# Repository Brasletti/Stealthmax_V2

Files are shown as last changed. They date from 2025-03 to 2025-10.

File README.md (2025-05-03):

# StealthMax V2 [RC1]– The New Filtration Beast!
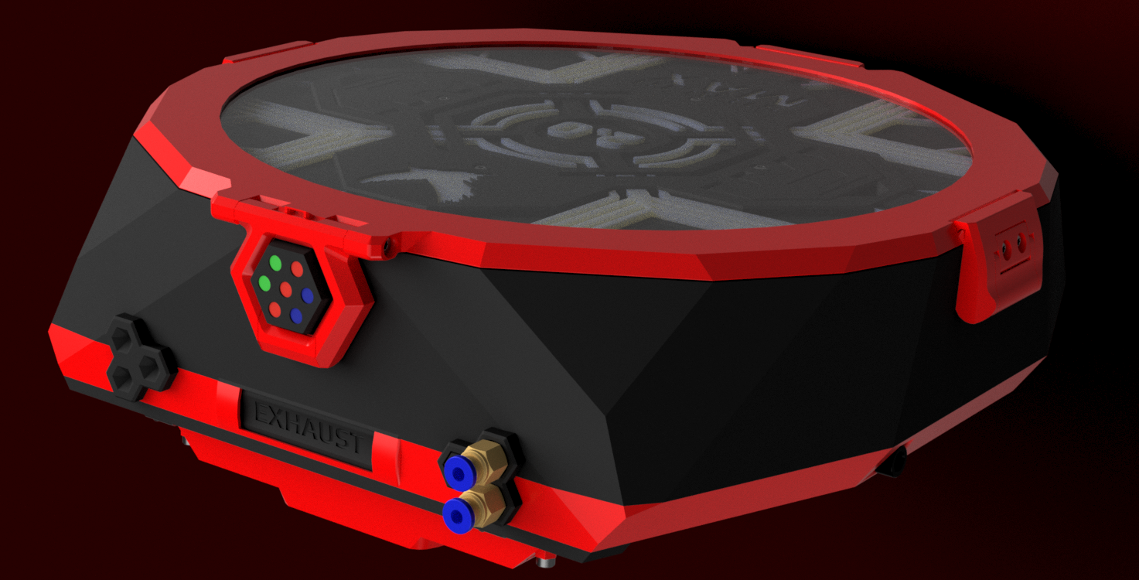
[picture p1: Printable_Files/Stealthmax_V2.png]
StealthMax V2

## Nevermore StealthMax was already the pinnacle of 3D printing filtration. How could we possibly improve it? Here's how:

---

## 🛡️ **The HEPA Filter**

A significant enhancement in filtration efficiency comes from adopting our new industrial-grade H14 HEPA filter, offering superior performance without compromising airflow. Gone are the days of relying on generic, uncertified robotic vacuum filters!

**Why the upgrade?**  
The Xiaomi robovac filters used in our V1 model lacked an official HEPA rating, typically indicating below-HEPA (≤H10) performance, casting doubt on their effectiveness in capturing ultra-fine particles (UFPs). Since FDM 3D printers primarily emit UFPs and volatile organic compounds (VOCs), using a filter specifically designed and rated to handle these pollutants efficiently is crucial.
<BR><BR>Some might be disappointed this is not an off-the-shelf component. While this is what we usually strive for, there are simply no H14 HEPA filters in a suitable size, and its especially hard (impossible?) finding H14 quality filtration at a price point below $12 - please check on amazon or the likes. At a (6-) 12 month per filter lifetime, Nevermore H14 is less than a dollar per month of use. We try to bring professional filtration to the home user, without charging a premium for it! 

Our new HEPA filter:
- Is **99.995% efficient** at capturing particulates (**H14 standard**).
- Outperforms typical robotic vacuum filters by capturing up to **2000 times more particulates** per filtration pass.
- Specifically excels at capturing ultra-fine particles (UFPs: PM0.01 – PM0.1) emitted during FDM 3D printing—particles that thinner, inferior filters struggle to handle effectively.
- Uses top and bottom sealing foam to force air through the filter and not pass through gaps in the filter unit.

**Nevermore3D proudly offers the highest-grade HEPA filtration available for FDM 3D printing. UFPs: YOU SHALL NOT PASS!**

---
## 🚀 **The Fan**

With the GPU fan from V1 becoming increasingly rare due to evolving GPU cooler designs, we searched far and wide for a powerful, reliable replacement capable of pulling substantial airflow through dense filtration media. **We found it!**

The new **StealthMax V2 7020 fan** (MX7020GBH2) delivers **twice the airflow** at the **same noise level**, meaning:
- Quieter operation at equivalent airflow.
- Efficient filtration of larger chamber volumes.
- Has twice the static pressure.

Moreover, by being slimmer than its predecessor it makes room for even more HEPA surface area, decreasing the pressure drop and maintaining maximum airflow! And since it's not an end-of-life (EOL) design, it should remain available for years to come! Also, contrary to any rumours, its certainly not proprietary!

---

## ⚙️ **The Servo-Controlled Vent**

While StealthMax V1 had an adjustable exhaust vent for controlling chamber temperatures when printing PLA, the solution wasn't optimal. Now, StealthMax V2 upgrades this feature with a **servo-controllable exhaust vent**, enabling:

- Automatic switching between exhaust and recirculation modes, tailored to your specific printing material.
- Chamber temperature management by venting air automatically whenever the chamber exceeds your specified temperature threshold.

---

## 💡 **Intelligent Signaling**

StealthMax V2 adds smart visual signaling (pending future software update), making it easy to monitor your filter status at a glance:

- **Neopixel LEDs** indicating filter function status and carbon replacement intervals.
- LEDs can be installed at the Bowden caps or the main hinge.
- Optional support for a sleek **1.28" LED display** or **KNOMI 2** mounted at the main hinge for the ultimate monitoring and customization experience (currently limited software support).

---

## 🔌 **Expanded Accessibility**

StealthMax V2 dramatically improves user accessibility and versatility:

- **Multiple Bowden tube access points** on every side for clean and easy routing.
- **Up to 6 simultaneous Bowden tubes** supported for complex tool-changer setups. Bowden routing is much improved too, reducing unneccessary filament drag.
- Integrated routing for your **PUG umbilical cable**.
- Convenient additional **CPAP intake ports** at the bottom, allowing flexible air routing throughout your machine.

---

## ❄️ **Carbon Cooler (Optional Add-On) [Kit ready: Summer 2025]**

Let's face it—activated carbon filtration becomes less effective as temperature rises, yet we require high chamber temperatures for optimal printing with most advanced filaments. StealthMax V2 is designed with this challenge in mind, supporting an optional **Carbon Cooler module**:

- **Peltier cooling** chills intake air, increasing carbon adsorption efficiency.
- The hot side of the peltier then **reheats the filtered air**, and is recirculated back into the chamber, maintaining a hot environment where needed.
- Cooler carbon means more effective filtration, capturing VOCs longer, even at chamber temperatures up to 70°C.
- Due to peltier inefficiencies, a bit more waste heat will be generated, so expect a slight bump in chamber temps too - but if your chamber gets too hot we have a servo exhaust for that!

**Cool carbon, hot chamber? Check.**

---

## 🌞 **PCO (Photocatalytic Oxidation) Stage (Optional Add-On) [Kit ready: Fall 2025]**

StealthMax V2 comes ready for integration of an advanced **internal photocatalytic oxidation (PCO)** filtration stage:

- Utilizes **UV light-created hydroxyl radicals** to destroy volatile organic compounds (VOCs) that bypass carbon and HEPA stages.
- Mimics natural sunlight degradation of VOCs in outdoor environments.
- Degraded VOC molecules become easier to capture with subsequent carbon filtration passes, ultimately breaking down into harmless CO₂.

**Sunlight truly is the best disinfectant!**

---

## ✨ **Additional Improvements**

We've implemented numerous improvements to ensure a smoother user experience and better performance:

- Enhanced **print-in-place latch designs** for reliable, hassle-free prints.
- **Carbon container lid** now sits more securely, with additional bolts and improved geometry.
- Reduced material usage in the main chamber, optimized support structures, quicker-to-print carbon basket, better fitting lid and generally more refined.

---

## 🚧 **Installation & Documentation**

[Central3DPrinting Electronics Installation](https://docs.google.com/presentation/d/e/2PACX-1vQseX6O0ZcSdXpOdnfkClK4V5FH0Ed1FzcuMa7BvOZgEiaAOtqwpyQ51u74DkXTCRRQ-EDv1vXZ-xWn/pub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)
Comprehensive installation guide, BOM (Bill of Materials), and detailed documentation for assembly will be provided shortly.
| Category | Item | Quantity | Notes |
|---|---|---|---|
| **Connectors**  | [Wago 221-413](https://s.click.aliexpress.com/e/_oDV7bC9) | 2 | |
| | [Wago 221-412](https://s.click.aliexpress.com/e/_oDV7bC9) | 2 | |
| | M6 PC4 Bowden connector | 1–6 | Typically 1; M10 optional at bottom slot only |
| **Fasteners** | M6 x 6mm | 2 | Plugs side PC4 M6 Bowden openings |
| | 2020 extrusion T-nut | 2 | |
| | M3 inserts (L=4 mm, OD=5 mm) | 42 | |
| | M2 x 6mm self-tapping screws | 5 | Pico + servo |
| | M3 x 6mm BHCS | 35 | Reduce quantity by 1 if not using intake sensor PCB |
| | M3 x 8mm SHCS | 1 | Omit if not using intake sensor sandwich |
| | M3 x 25mm SHCS | 8 | |
| | M3 x 6mm FHCS | 4 | Reduce quantity by 1 if not using spacer for 3mm back panels |
| | M3 x 10mm BHCS | 3 | |
| | M3 x 16mm SHCS | 4 | |
| **Electronics** | Same as StealthMax V1 | - | Excludes buck converter; replaces DC plug+BT with Microfit 5p for USB; adds Pico pins GP12-15 for Neopixel and FT90M servo |
| |[7-bit neopixel hinge display](https://s.click.aliexpress.com/e/_oorL68t) | 1 | Optional. |
| |[1,28" hinge display](https://s.click.aliexpress.com/e/_olAkf37) | 1 | Optional. Touch version without touch cables easier to install. Non-touch version needs thinner [awg 28 wires](https://s.click.aliexpress.com/e/_oFYgT37) to fit in the slot |
| |[FT90M Servo](https://s.click.aliexpress.com/e/_ol1TsBr) | 1 | Standard slot will fit FT90M, FT1190M servos. Version for [Emax ES08MA and MDII servos](https://s.click.aliexpress.com/e/_olzGGzx) also available |
| **Fan** | [TopFan MX7020GBH2](https://central3dprinting.com/products/nevermore-stealthmax-v2-fan?ref=NEVERMORE3D) | 1 | Will also fit the Sanyo C70 |
| **HEPA** | [Nevermore H14 HEPA](https://central3dprinting.com/products/nevermore-stealthmax-v2-h14-hepa-filter?ref=NEVERMORE3D) | 1 | 116mm OD x 42mm H |
| **Carbon** | [Nevermore](https://central3dprinting.com/products/nevermore-activated-carbon-for-voc-standard-xl-scorch?ref=NEVERMORE3D) | 1 | Nevermore Carbon, Nevermore Boost, Nevermore Scorch, or any tested quality, non-acid, 4mm activated carbon pellet. 2L will refill with some to spare. |

---

## 📢 **Community & Support**

We're dedicated to continuously improving StealthMax V2. Your feedback, testing, and suggestions are invaluable. Connect with us:

- **GitHub Issues:** Report issues or request enhancements directly here on GitHub.
- **[Discord Community](https://discord.gg/RgQP5cWHxj):** Join fellow makers and contributors for discussions, troubleshooting, and feature discussions.
- **[Check our Print Settings Wiki](https://github.com/nevermore3d/StealthMax/wiki/Print-Settings)** for additional tips and tricks!

---

**Happy printing, breathe easy, and stay stealthy!** 🚀🌬️
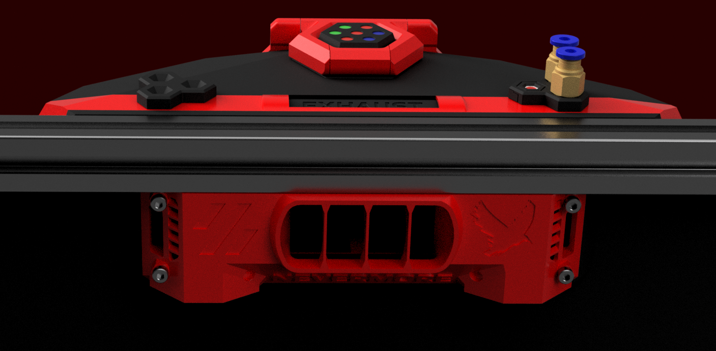
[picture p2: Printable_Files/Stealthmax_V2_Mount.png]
StealthMax V2 Mount


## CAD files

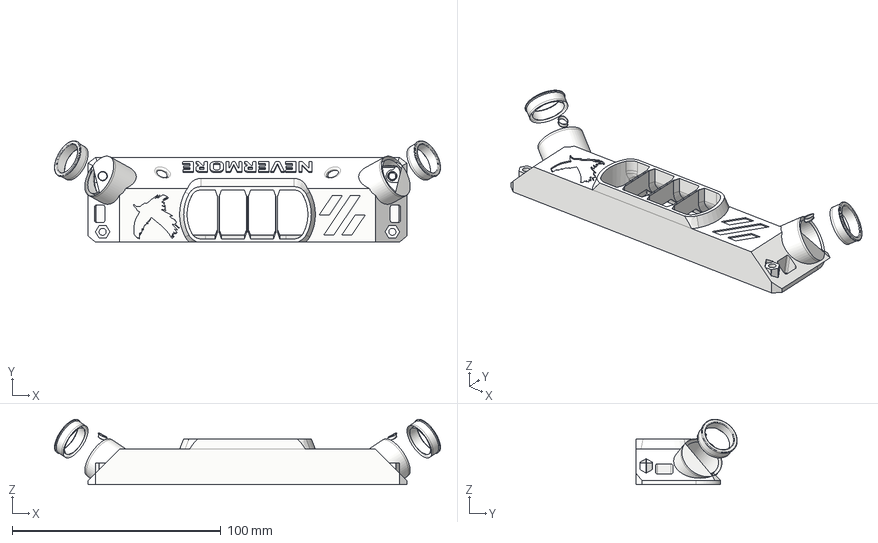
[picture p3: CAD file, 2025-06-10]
Printable_Files/0_Chamber_Side_Mounting/CPAP_Intakes/17mm_CPAP_Tube.step
185.0 x 48.7 x 31.3 mm

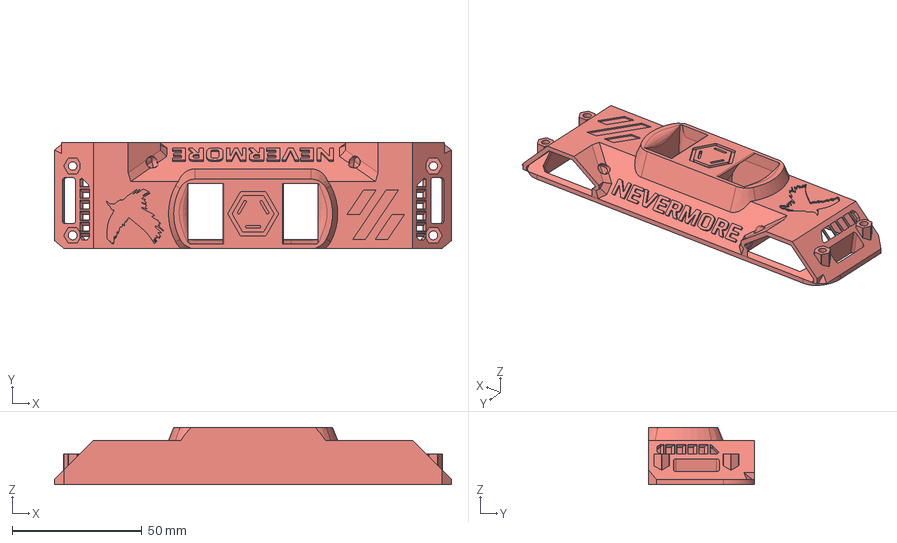
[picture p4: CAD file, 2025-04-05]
Printable_Files/0_Chamber_Side_Mounting/Exhaust_Diverter/EXHAUST_LATERAL_DIVERT(moving_bed).step
152.8 x 40.7 x 22.0 mm

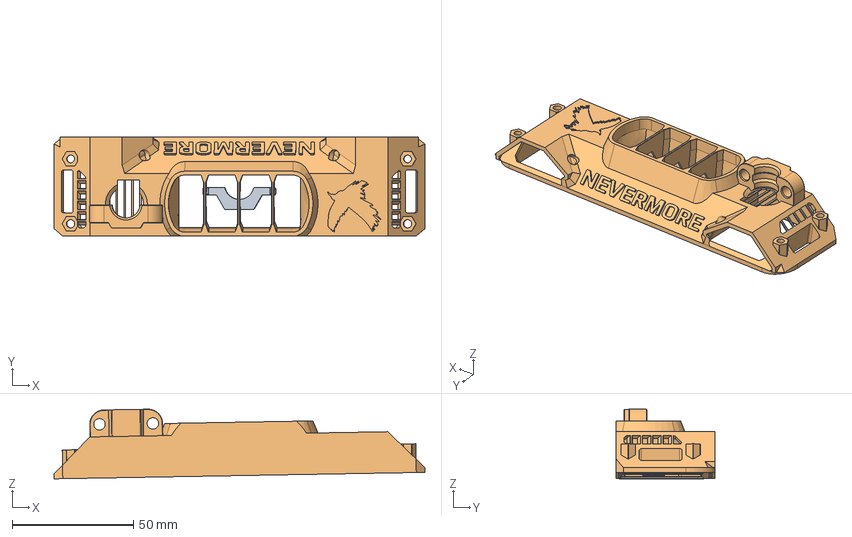
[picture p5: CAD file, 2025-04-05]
Printable_Files/0_Chamber_Side_Mounting/PUG_Wire_Routing/PUG_Chamber_Side.step
152.8 x 40.7 x 28.7 mm

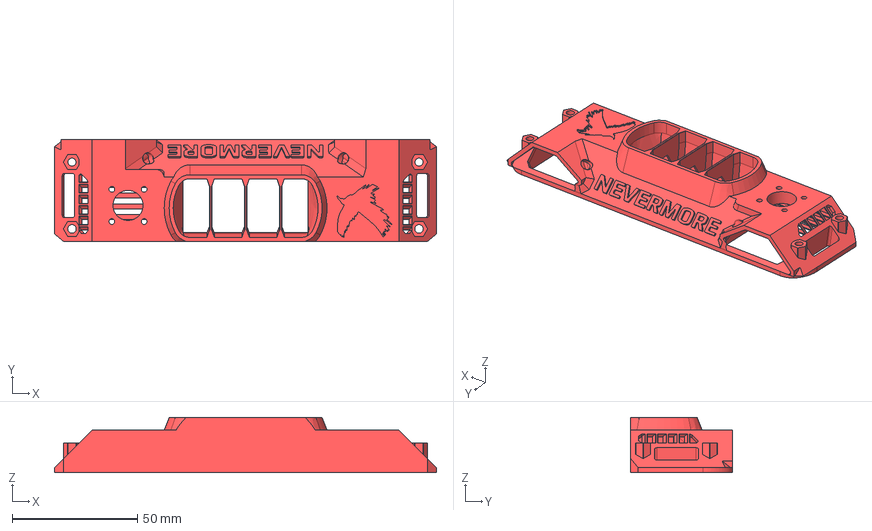
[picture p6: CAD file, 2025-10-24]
Printable_Files/0_Chamber_Side_Mounting/UserMods/Umbilical_CNLINKO_LP-12_Socket[Brasletti]/umbilical_cnlinko_lp12_intake.step
152.8 x 40.7 x 22.0 mm

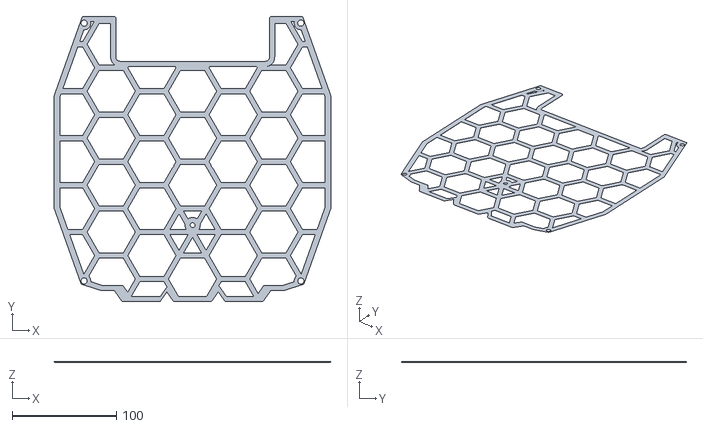
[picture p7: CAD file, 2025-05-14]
Printable_Files/1_Flow_Chamber/Back_Panel_Spacer[for_3mm_back_panel_thickness].stl
265.4 x 273.1 x 1.00

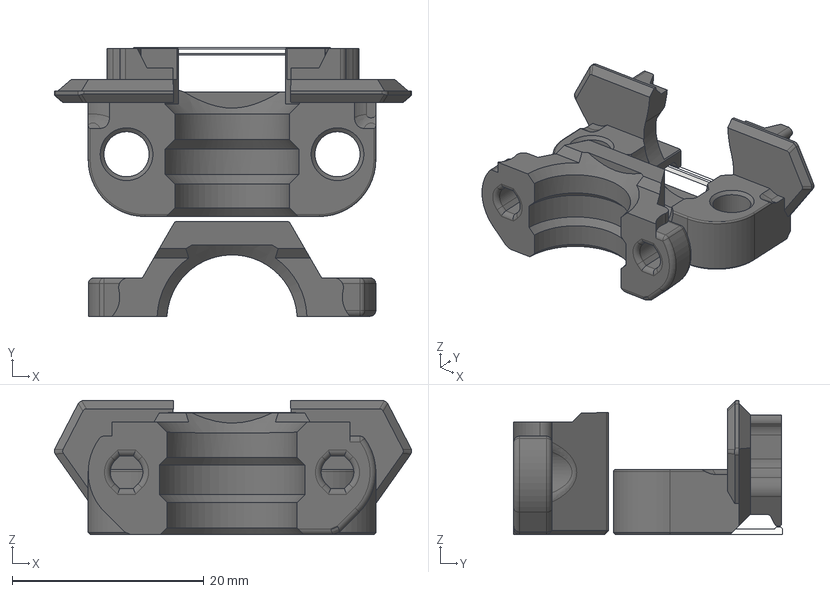
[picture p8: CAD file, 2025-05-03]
Printable_Files/1_Flow_Chamber/Bottom_Port_Options/PUG_Port_Cover.step
37.2 x 28.0 x 14.0 mm

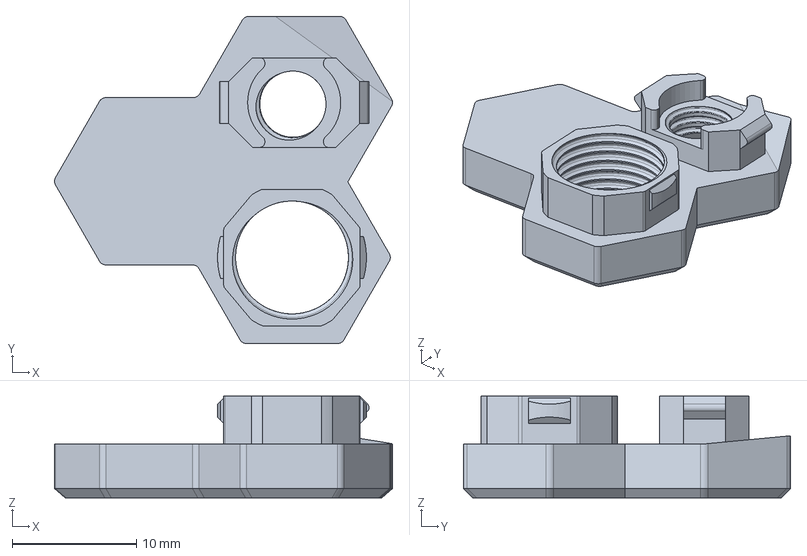
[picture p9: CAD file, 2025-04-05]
Printable_Files/1_Flow_Chamber/Bowden_Tube_Intake_Options/Left/[LEFT]Low_M10_PC4_noLED_High_M6_PC4.step
27.2 x 26.4 x 8.20 mm

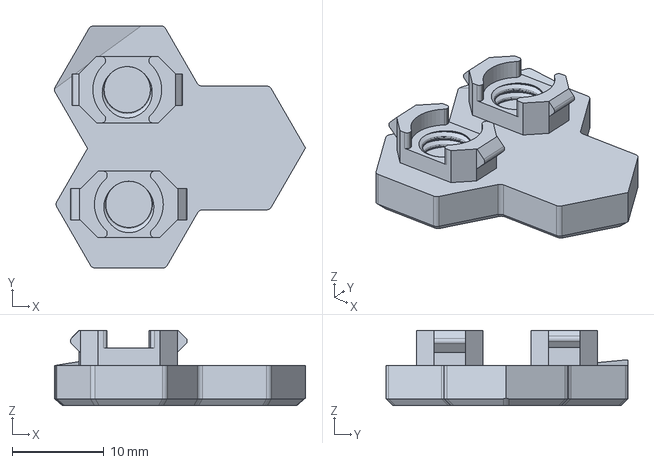
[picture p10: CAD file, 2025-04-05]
Printable_Files/1_Flow_Chamber/Bowden_Tube_Intake_Options/Right/Triple_Blank.step
27.3 x 26.4 x 8.20 mm

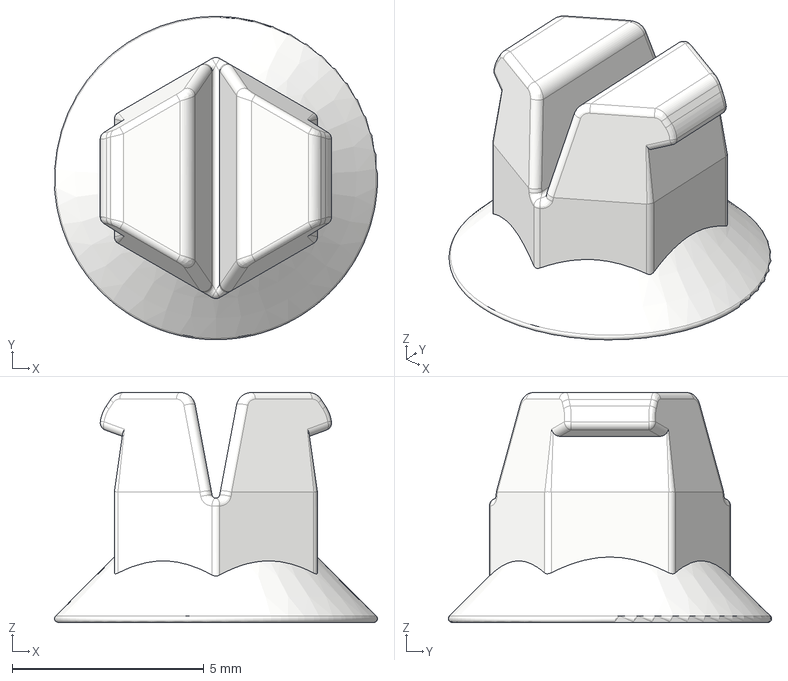
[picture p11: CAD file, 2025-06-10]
Printable_Files/1_Flow_Chamber/Bowden_Tube_Intake_Options/Side_Bowden_Hex_Plug(2x).step
8.43 x 8.43 x 6.00 mm

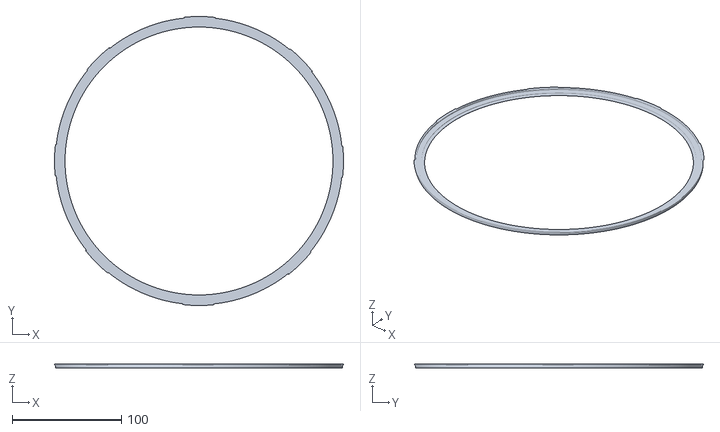
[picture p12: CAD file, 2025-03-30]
Printable_Files/3_Lid_and_Latches/Acrylic_Retainer_250mm.stl
264.8 x 264.8 x 3.40

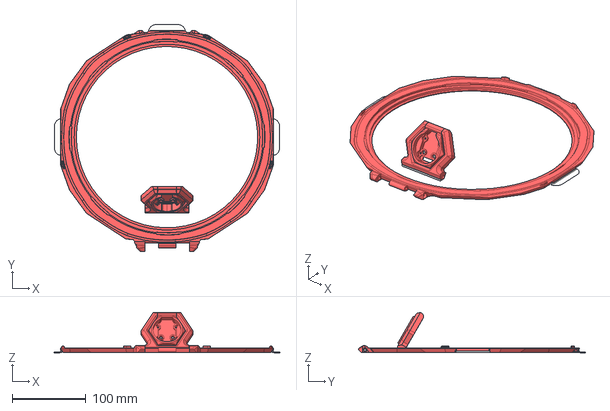
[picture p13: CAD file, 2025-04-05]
Printable_Files/3_Lid_and_Latches/Main_Hinge_Options/1,28_Display_Hinge/Touch_Screen_Hinge.step
304.7 x 307.2 x 54.5 mm
Hinge
M_3.0_Support (1) (1) x 3

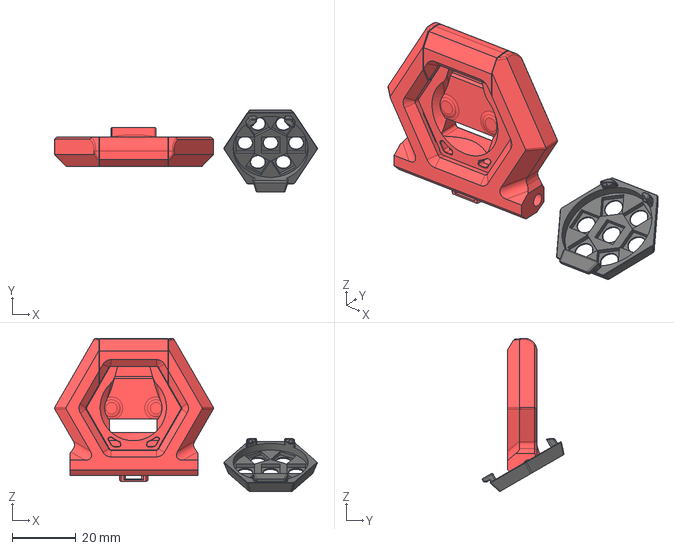
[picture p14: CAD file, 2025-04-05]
Printable_Files/3_Lid_and_Latches/Main_Hinge_Options/Neopixel_Hinge/neopixel_hinge.step
82.5 x 25.8 x 48.1 mm
support (1) (1) (1)
PixelHolder (1) (1)

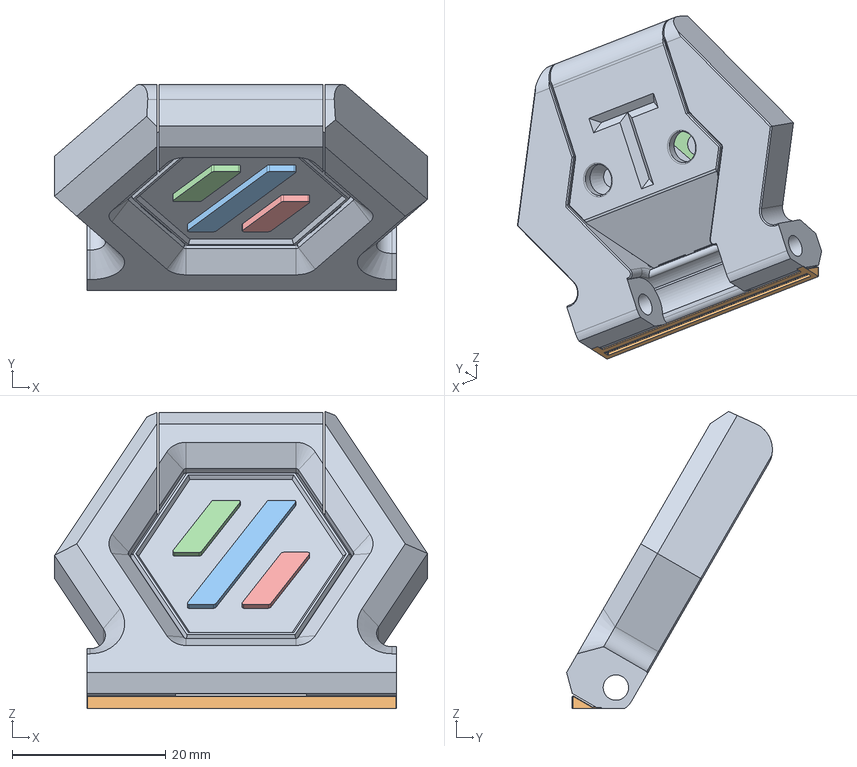
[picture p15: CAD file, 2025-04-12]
Printable_Files/3_Lid_and_Latches/Main_Hinge_Options/Standard_Printed_Hinge/LidFrontHinge.step
48.5 x 26.8 x 38.6 mm

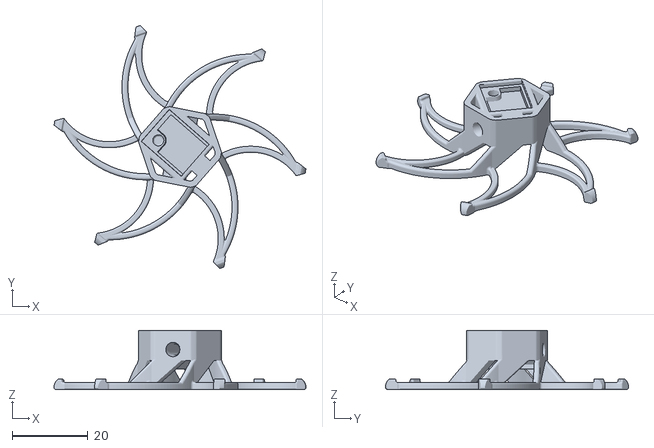
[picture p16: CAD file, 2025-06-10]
Printable_Files/Sensor_Sandwich_Hexopus.stl
66.3 x 64.0 x 15.7

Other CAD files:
Printable_Files/0_Chamber_Side_Mounting/Standard_Intake_Exhaust.step
Printable_Files/0_Chamber_Side_Mounting/UserMods/Umbilical_CNLINKO_LP_16_Socket[kitokirisaki]/umbilical_cnlinko_lp16_intake.step
Printable_Files/0_Chamber_Side_Mounting/CPAP_Intakes/CPAP_Tube_2020_Extrusion_Mount.stl
Printable_Files/1_Flow_Chamber/Bottom_Port_Options/5p_Microfit.step
Printable_Files/0_Chamber_Side_Mounting/CPAP_Intakes/22mm_CPAP_Tube(LastZeanon)).step
Printable_Files/0_Chamber_Side_Mounting/UserMods/Umbilical_CNLINKO_LP_16_Socket[kitokirisaki]/umbilical_cnlinko_lp16_intake.stl
Printable_Files/1_Flow_Chamber/Bottom_Port_Options/17mm_ID_CPAP_intake_tube.step
Printable_Files/1_Flow_Chamber/Bottom_Port_Options/22mm_ID_CPAP_intake_tube.step
Printable_Files/1_Flow_Chamber/Bottom_Port_Options/3p_Microfit.step
Printable_Files/1_Flow_Chamber/Bottom_Port_Options/PC6_Bottom_Bowden.step
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

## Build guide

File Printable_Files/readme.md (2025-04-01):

## Printable Files
Welcome to the printable files repo. It contains the needed parts to print your own beta Stealthmax V2 unit! If you dont see a certain piece in the folders, it might be part of the Extra_Pieces STL in this root folder. If you want to change out any of these pieces, you can use the split to parts command in your slicer.
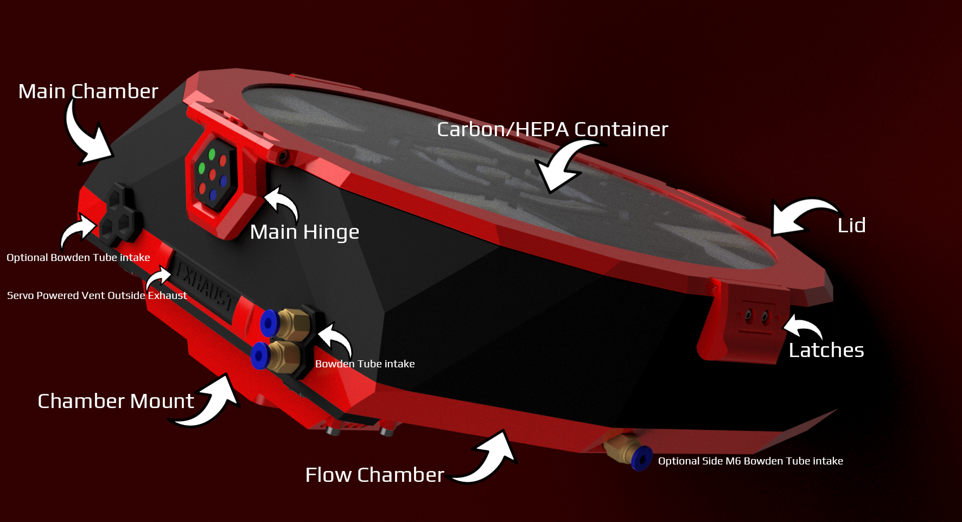
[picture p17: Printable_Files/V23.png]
StealthMax V2


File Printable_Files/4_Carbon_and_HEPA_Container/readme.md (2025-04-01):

## Carbon and H14 HEPA Container
The carbon container - or "basket" - holds up to a kilogram of carbon - enough to capture bad stuff from your printer for up to six months! It also holds an industrial grade H14 Hepa filter, capturing 99.995% of particulates emitted by your printer - per pass, and upp to 2000x more UFPs than the regular cheap robovac "HEPA"! 

How come regular hepa+carbon filters has a 6 month rating despite containing a few grams of carbon? Yeah, thats just bull.  
At any moment, the air in your room will contain tens of grams of different kinds of VOCs - that a few grams of carbon sprinkled on most combined HEPA+Carbon filters can catch VOCs for six months is made up (the HEPA part will last that long, however). Stealthmax is dimensioned to adhere to physics.
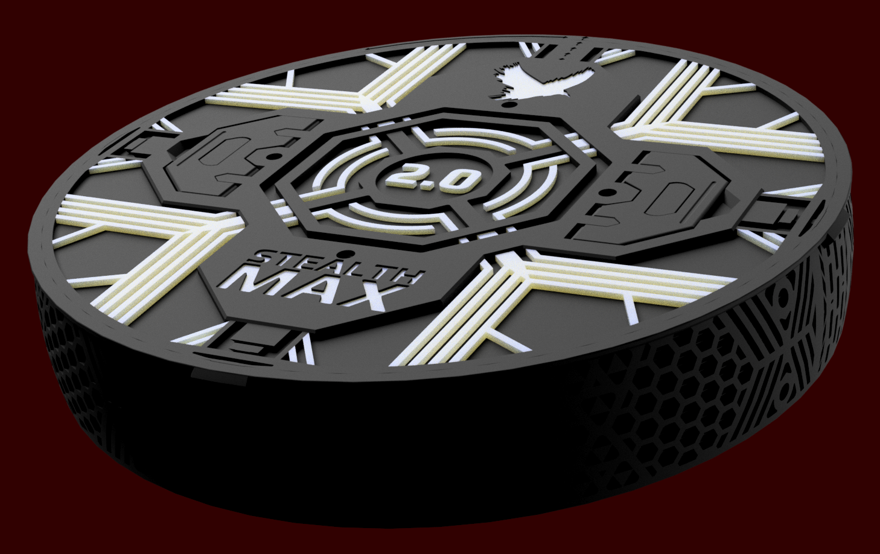
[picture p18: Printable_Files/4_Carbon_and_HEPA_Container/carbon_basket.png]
StealthMax V2


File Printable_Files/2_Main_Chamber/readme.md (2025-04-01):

## Main Chamber
The Main Chamber of the Stealthmax contains the removable carbon/H14 HEPA container, houses the slot for the sealing foam cord between main chamber and lid, as well as the electronics access latches and center hexopus air sensor carrier.
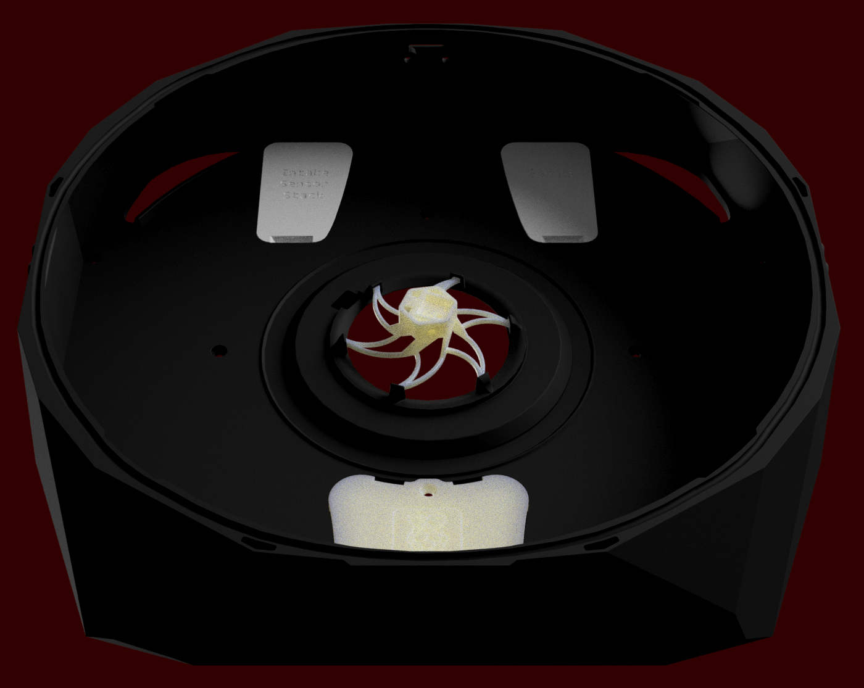
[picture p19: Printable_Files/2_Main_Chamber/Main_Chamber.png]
StealthMax V2


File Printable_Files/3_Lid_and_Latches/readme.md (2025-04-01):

## Lid and latches
The Lid is the top part in the stealthmax sandwich. It holds the 250mm acrylic panel, and is compressed onto the Main chamber by the three latches + main hinge. Underneath the lid piece sits the acrylic panel retainer pice, holding the acrylic panel in place (preferably with the help of some RTV or glue for an optimal seal).
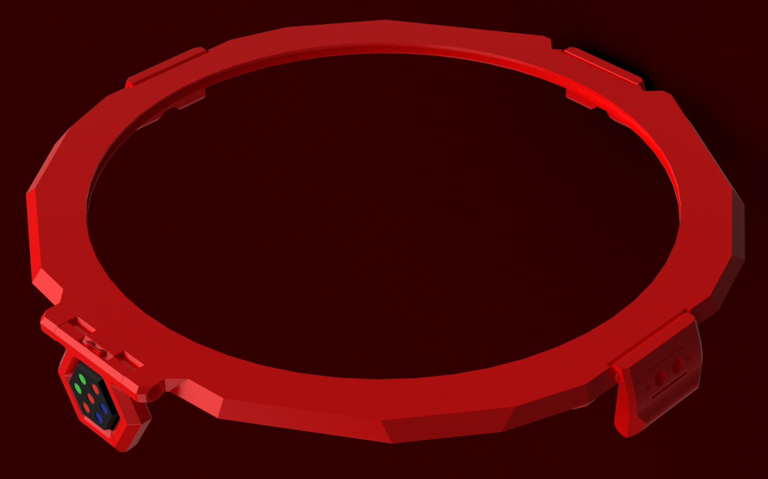
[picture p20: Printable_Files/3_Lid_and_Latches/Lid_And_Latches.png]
StealthMax V2


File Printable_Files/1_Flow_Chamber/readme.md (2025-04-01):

## Flow Chamber
The Flow Chamber forms the bottom component of the StealthMax sandwich. It efficiently **splits and funnels intake air** to the Main Chamber, ensuring even carbon wear. This section also **houses the main fan** that powers the unit, drawing air through the carbon/HEPA container and subsequently exhausting or recirculating it into the enclosure or hot chamber, and **the electronics bay** with pi pico and wago connectors.
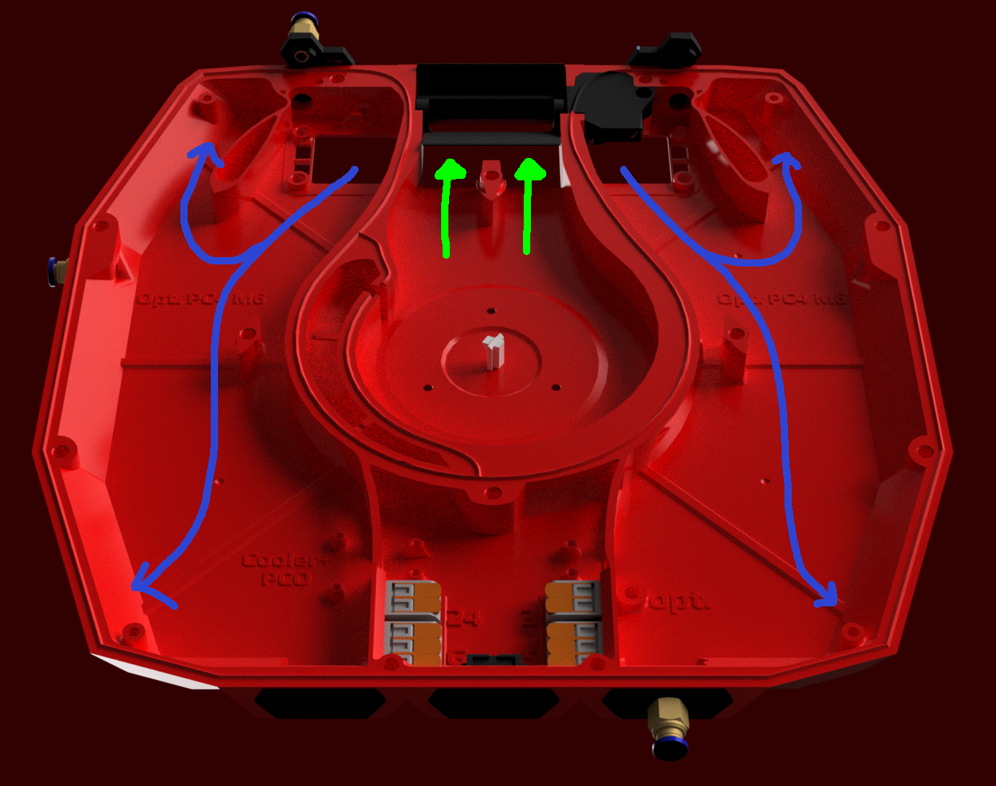
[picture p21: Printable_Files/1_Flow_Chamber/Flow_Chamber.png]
StealthMax V2


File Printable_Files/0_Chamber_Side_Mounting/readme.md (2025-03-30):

## The mounting piece installs inside your printer, connecting your external StealthMax unit directly to the heated chamber.

It draws in contaminated air (indicated by blue arrows) and returns clean, filtered air back into the heated chamber (green arrows). 
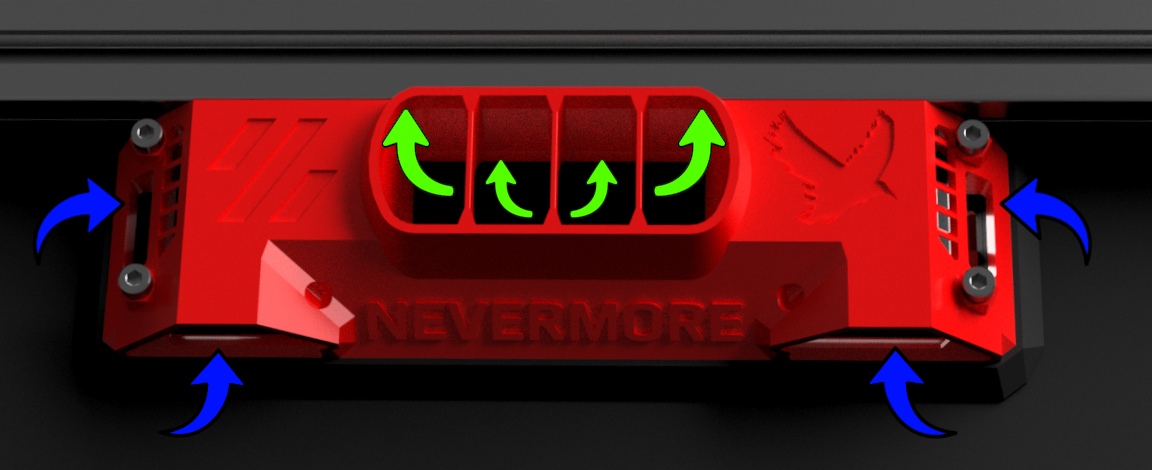
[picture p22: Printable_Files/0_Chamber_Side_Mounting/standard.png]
StealthMax V2

Image shows the standard Chamber Mount, some variations are available (see directories above). Currently, only the Voron-sized back panel mount is available.

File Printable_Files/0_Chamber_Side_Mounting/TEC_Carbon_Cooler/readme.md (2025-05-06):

## TEC Carbon Cooler

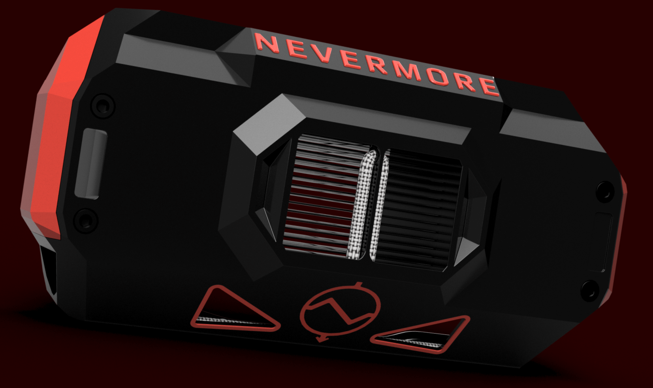
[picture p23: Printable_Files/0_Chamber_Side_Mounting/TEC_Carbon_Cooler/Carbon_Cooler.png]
StealthMax V2

_In development/testing. Check the carbon cooler beta channel on nevermore discord._ 

Utilizes Peltier elements to cool the filter intake air, enhancing the filtration efficiency and extending the lifespan of your activated carbon filtration media. The filtered, cool air is then passed over the hot side of the Peltier element to dissipate heat, simultaneously reheating the air as a beneficial byproduct, before being recirculated into the chamber to sustain a warm environment where needed. Due to the inefficiency of Peltier cooling, more heat than cooling is generated, resulting in waste heat being released into the chamber and causing a net temperature increase.

In combination with the servo exhaust vent and bedfans, the Peltier Carbon Cooler allows for active chamber temperature control from passive/waste heat sources in combination with chamber exhaust ventilation.

**Designed with safety in mind!**
* Thermistor thermo regulation on both hot and cold sides, ensuring safe cooling and hot-side operation below glass transition temperatures.
* Stealthmax temp/humidity sensors calculates dew points, to avoid risk of condensation inside the machine.
* In case of electrical malfunction (or user override), a built-in drip tray catch any condensation, wicking it to the hot exhaust air stream for evaporation.

_Note on power requirements and additional safety considerations_:   
* The TEC Carbon Cooler will require up to 100 watts of power to run at full capacity, generating up to 50W of carbon cooling and 50W of chamber (waste) heating.
* For most users, this means an additional 24V power supply will be needed, unless software limited power consumtion.
* Note that Peltier elements as a chamber heat source are much safer than resistive/PTC heating, because they operate without the risk of runaway high temperatures or exposed heating elements, and their failure mode typically results in the entire TEC element ceasing to function.
* The two TEC elements in the TEC Cooler are wired in series to ensure the circuit breaks as soon as a TEC element fails (Peltier elements generally last many years).

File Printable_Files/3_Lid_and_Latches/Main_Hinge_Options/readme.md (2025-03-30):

## Main Hinge
There are several hinges to chose from this time around. The regular printed one from stealthmax V1, a 7-pixel neopixel one for status signalling, or even a few oversized versions that fit 1,28" displays.
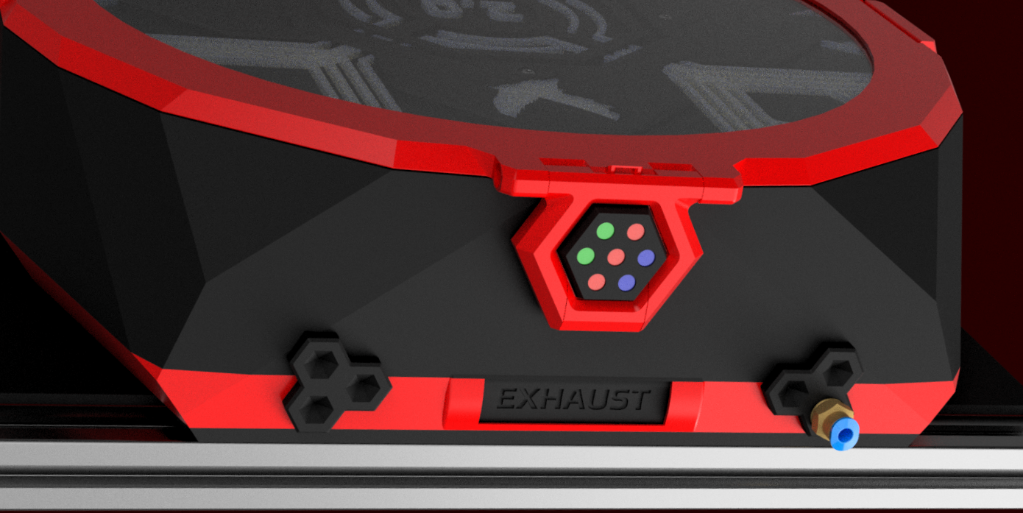
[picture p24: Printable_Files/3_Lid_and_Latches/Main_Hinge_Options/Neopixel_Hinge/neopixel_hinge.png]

Neopixel status hinge.
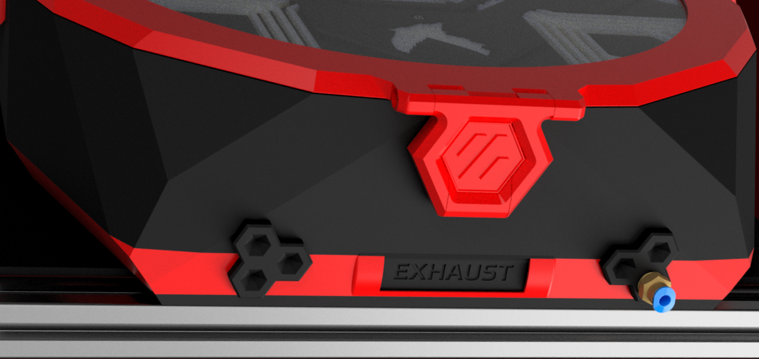
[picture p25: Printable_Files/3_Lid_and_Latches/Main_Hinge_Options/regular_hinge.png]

Regular printed, no-fuzz hinge.
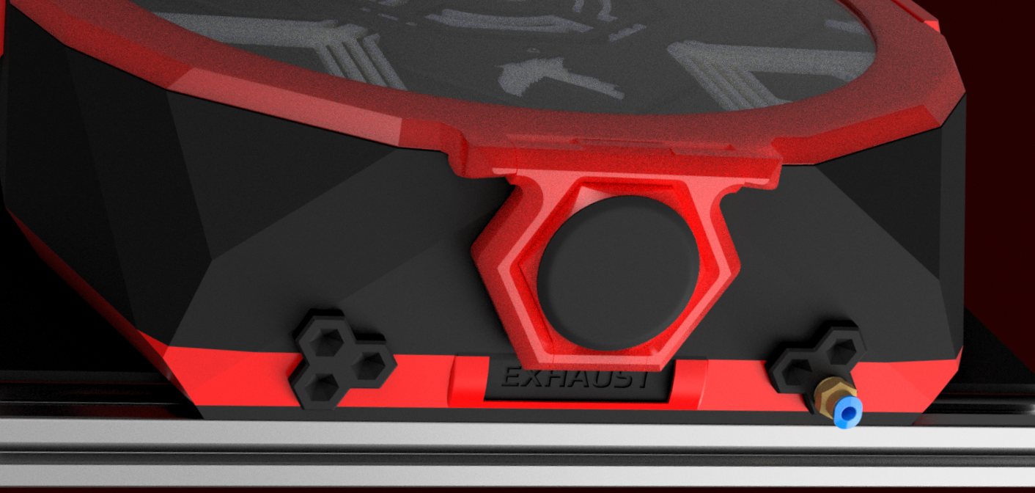
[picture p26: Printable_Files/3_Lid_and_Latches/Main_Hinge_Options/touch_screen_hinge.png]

1,28" hinge.

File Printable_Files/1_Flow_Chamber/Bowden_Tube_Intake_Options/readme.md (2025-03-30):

## Bowden_Tube_Intake_Options
There are two main Bowden tube connection points on the Stealthmax (as well as and optional connection points on the side and bottom covers, for a theoretical 8 entry points)
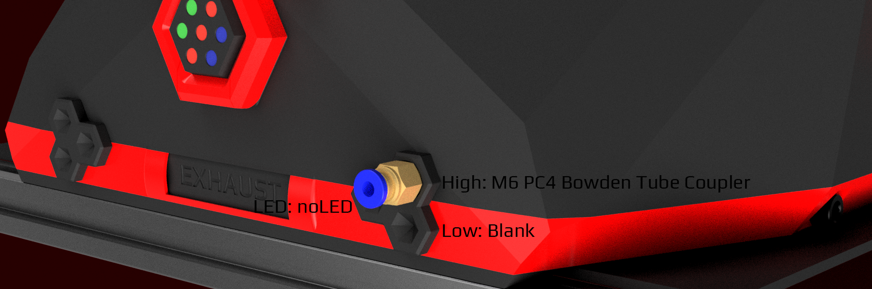
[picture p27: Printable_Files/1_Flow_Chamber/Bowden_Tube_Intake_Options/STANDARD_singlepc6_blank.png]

Standard setup with blank port covers on the left, and a single PC4 M6 in the top position on the right.  

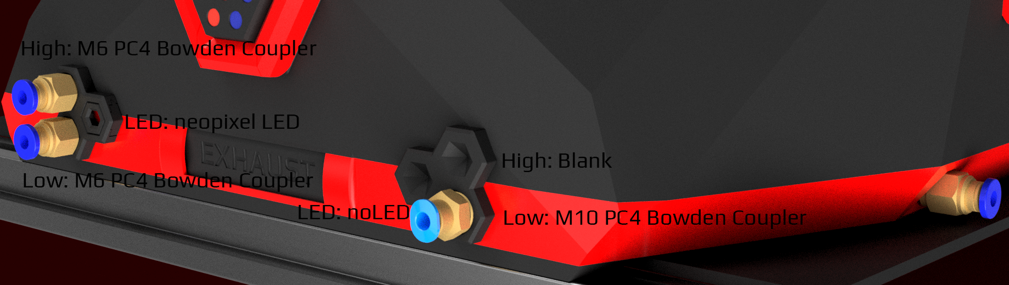
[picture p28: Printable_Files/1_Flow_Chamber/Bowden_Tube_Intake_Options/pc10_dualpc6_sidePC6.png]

Ports exist for M10/M6 PC4 bowden couplers, and the optional singe neopixel/SB LED in the center position that can be used for status signalling.

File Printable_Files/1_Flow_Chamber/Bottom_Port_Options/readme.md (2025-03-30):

## Bottom Ports
There are three bottom ports on the Stealthmax. The side ones usually has only covers, but can be used for supplemental functions. The center one is usually the main power/data connection.
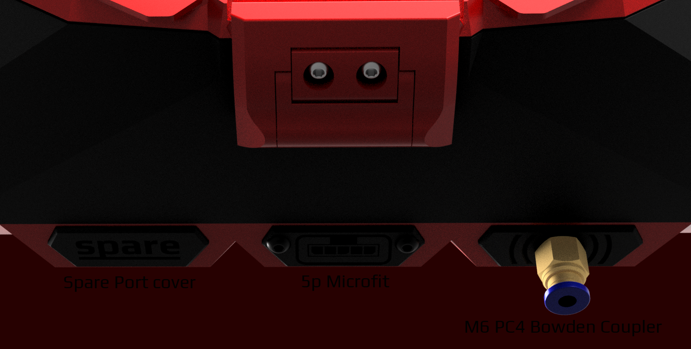
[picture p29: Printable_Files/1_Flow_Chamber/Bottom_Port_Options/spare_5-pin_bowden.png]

Left: Spare Cover. Center 5-pin Microfit (for USB connected stealthmax). Right: M6 PC6 Bowden Coupler for users who like to add filament from below. 

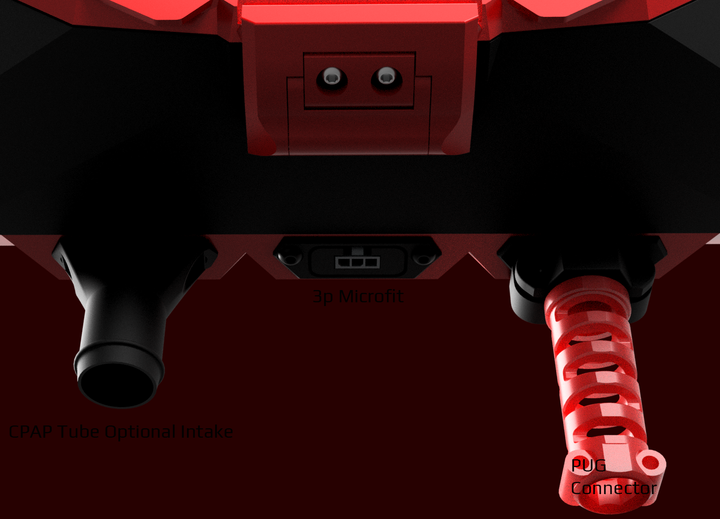
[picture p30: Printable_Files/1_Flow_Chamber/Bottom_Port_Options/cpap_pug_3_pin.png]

Left: CPAP tube intake (duct an intake to anywhere on the machine exteriorly, should be used on both sides for even airflow). Center 3-pin Microfit (for BT connected stealthmax).  Right: PUG Port Cover, for routing umbilicals through the stealthmax.

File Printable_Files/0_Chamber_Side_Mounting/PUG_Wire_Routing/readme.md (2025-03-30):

## PUG Umbilical

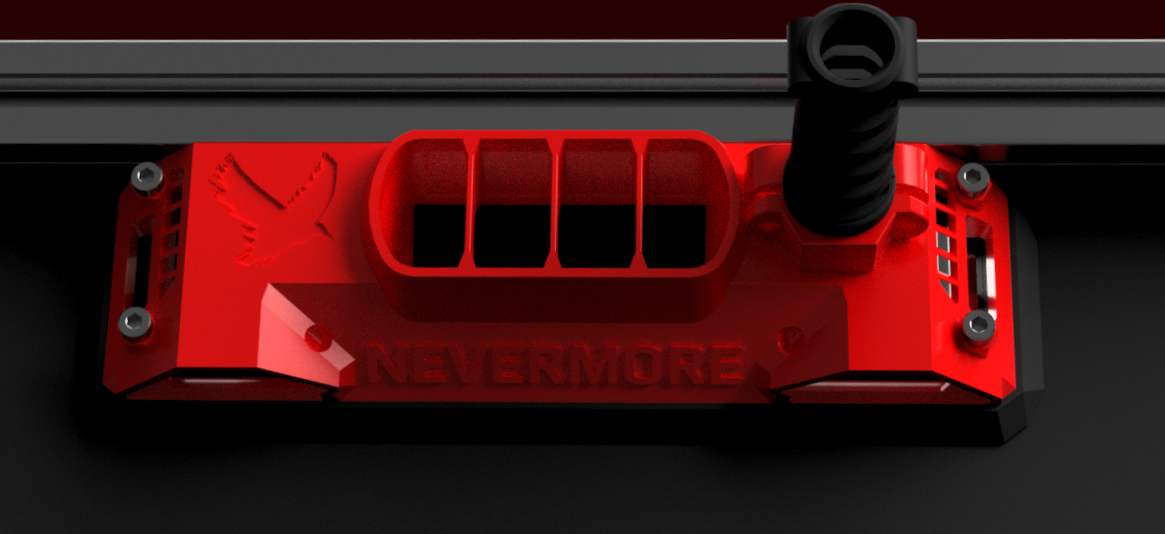
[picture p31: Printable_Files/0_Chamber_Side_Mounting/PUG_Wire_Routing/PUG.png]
StealthMax V2

This Mount adds a PUG connector. Ideal for routing your umbilical through the stealthmax (pair with PUG bottom port).

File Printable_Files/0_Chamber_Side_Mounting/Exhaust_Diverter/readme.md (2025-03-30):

## Exhaust Diverter

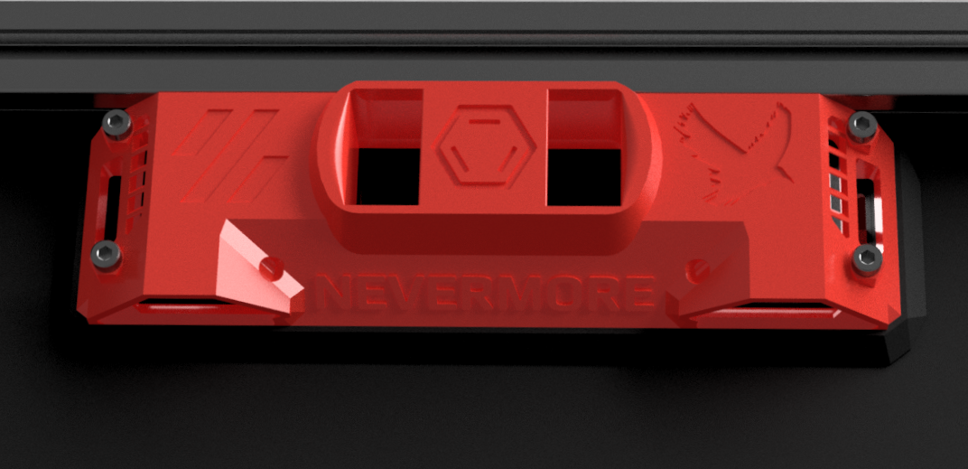
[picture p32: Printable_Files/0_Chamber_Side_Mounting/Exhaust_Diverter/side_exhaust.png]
StealthMax V2

This Mount splits the exhausted air stream from the center to the sides. It can be useful for moving bed setups, where you want to avoid an air stream very close to your printed parts (potentially causing overcooling / wapring issues).

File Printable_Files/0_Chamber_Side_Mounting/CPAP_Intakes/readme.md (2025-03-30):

## CPAP Intakes

This Mount fits CPAP tubes, that can be ducted to the gantry to suck dirty fumes closer to where theyre created.
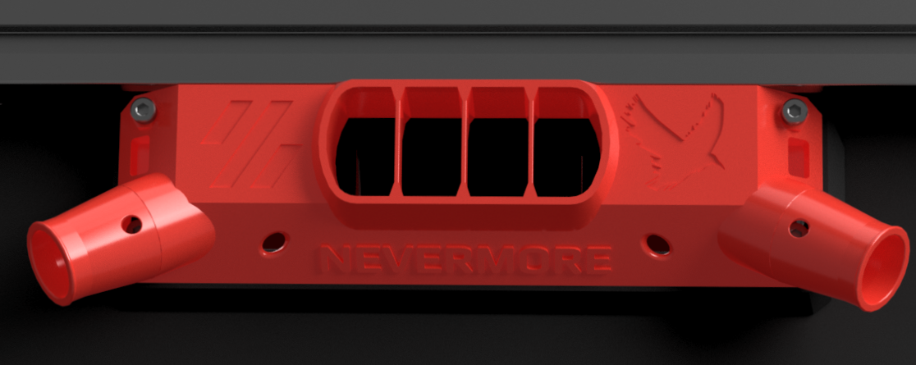
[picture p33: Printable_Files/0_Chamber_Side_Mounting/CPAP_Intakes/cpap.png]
StealthMax V2

Image shows the 17mm CPAP Mount.

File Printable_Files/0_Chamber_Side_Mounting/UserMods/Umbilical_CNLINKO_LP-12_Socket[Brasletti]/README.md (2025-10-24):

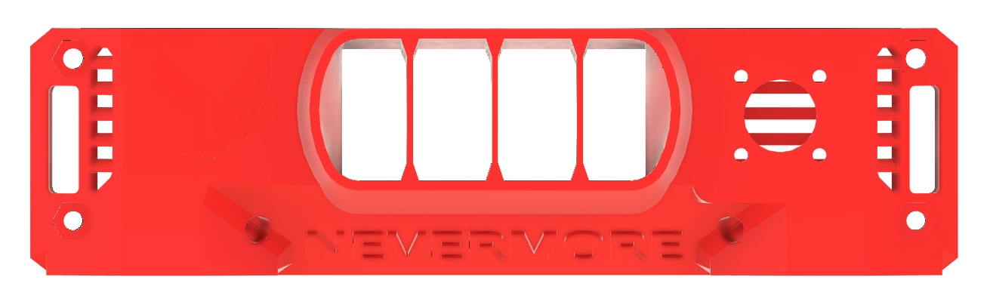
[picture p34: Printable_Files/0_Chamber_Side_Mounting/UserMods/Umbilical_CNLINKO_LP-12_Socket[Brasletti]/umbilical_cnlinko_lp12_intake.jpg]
CAD RENDER

# StealthMax V2 CNLINKO LP-12 Umbilical Mod

This mod enhances the StealthMax V2 with a redesigned intake that integrates a CNLINKO LP-12 umbilical for cable management.

## Features

* **Integrated Umbilical:** The CNLINKO LP-12 connector provides a durable and convenient single-point connection for all toolhead wiring.

---

## Bill of Materials (BOM)

To replicate this mod, you'll need the following:

* **CNLINKO LP-12 Connector:** You are free to use how many pin's you want. In my case I used a LP-12-J04SX-02-401
* **Wiring:** Appropriate gauge wires for your specific components (heaters, thermistors, fans, etc.).
* **Printed Parts:** `umbilical_cnlinko_lp16_intake.stl`
* **Fasteners:**
    Provided with the Connector Socket

---

## Gallery

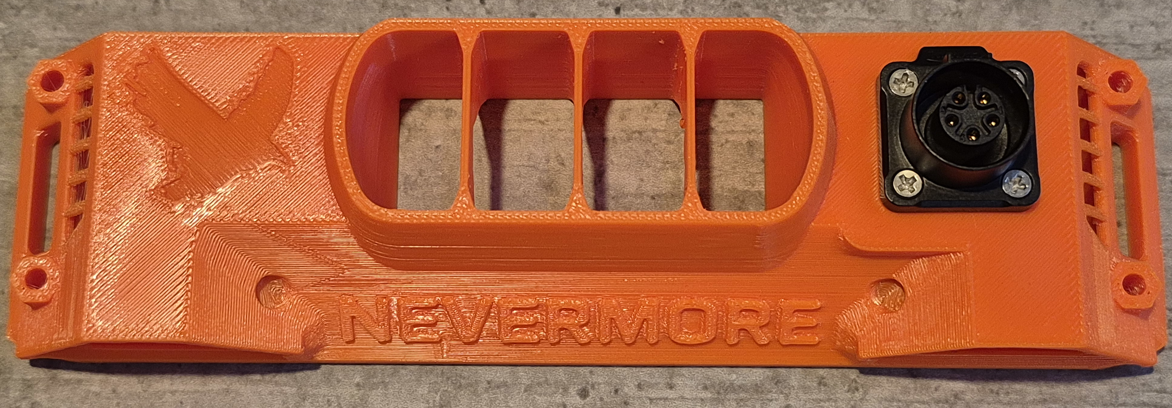
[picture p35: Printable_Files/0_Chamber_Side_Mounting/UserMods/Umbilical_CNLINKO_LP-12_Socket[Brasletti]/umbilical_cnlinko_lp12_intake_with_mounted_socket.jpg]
With Socket

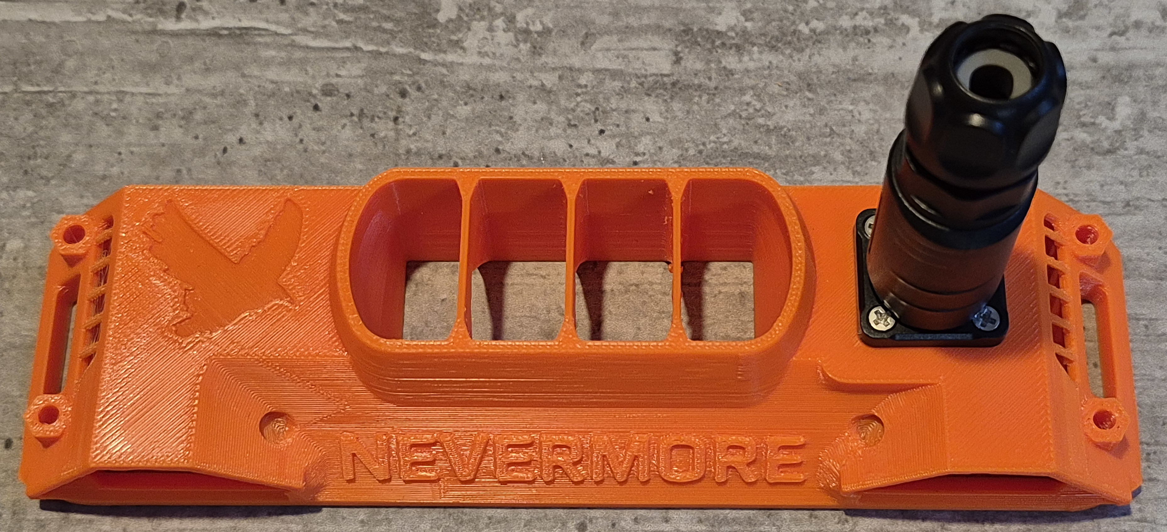
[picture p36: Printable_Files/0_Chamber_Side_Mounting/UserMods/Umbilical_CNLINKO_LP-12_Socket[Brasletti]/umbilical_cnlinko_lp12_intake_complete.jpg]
With Plug

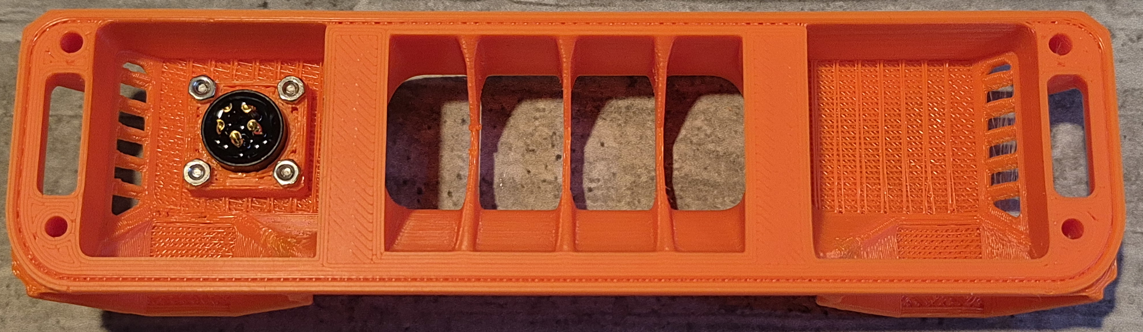
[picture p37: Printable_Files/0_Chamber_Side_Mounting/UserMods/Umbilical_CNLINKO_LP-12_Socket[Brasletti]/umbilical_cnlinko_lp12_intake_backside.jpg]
Backside


---

## Support & Contributions

If you have any questions or suggestions, feel free to ask me (@joebar77) in the Nevermore Discord. Contributions and improvements are always welcome!

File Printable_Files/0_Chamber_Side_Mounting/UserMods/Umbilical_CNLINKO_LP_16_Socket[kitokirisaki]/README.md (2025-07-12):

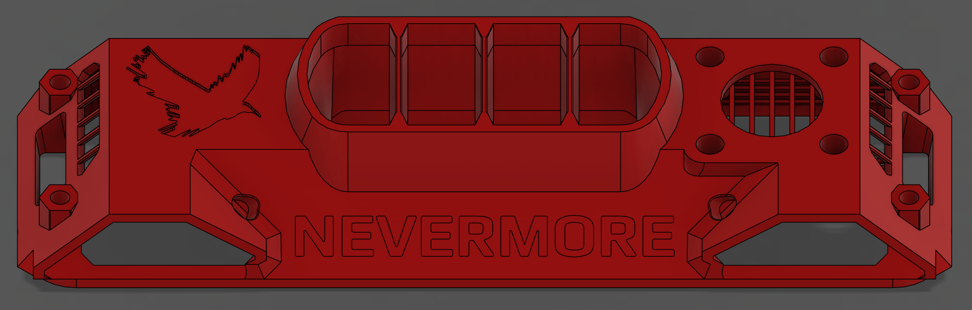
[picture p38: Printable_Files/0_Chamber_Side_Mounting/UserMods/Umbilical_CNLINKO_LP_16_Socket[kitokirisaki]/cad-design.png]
CAD RENDER

# StealthMax V2 CNLINKO LP-16 Umbilical Mod

This mod enhances the StealthMax V2 with a redesigned intake that integrates a robust CNLINKO LP-16 umbilical for cable management.

## Features

* **Integrated Umbilical:** The CNLINKO LP-16 connector provides a durable and convenient single-point connection for all toolhead wiring.

---

## Bill of Materials (BOM)

To replicate this mod, you'll need the following:

* **CNLINKO LP-16 Connector:** You are free to use how many pin's you want. In my case I used a LP-16-J08SX-02-401
* **Wiring:** Appropriate gauge wires for your specific components (heaters, thermistors, fans, etc.).
* **Printed Parts:** `umbilical_cnlinko_lp16_intake.stl`
* **Fasteners:**
    - 4 FHCS M3 x 8mm
    - 4 Voron Sized Heat Inserts (M3 x 4 x 5)

---

## Gallery

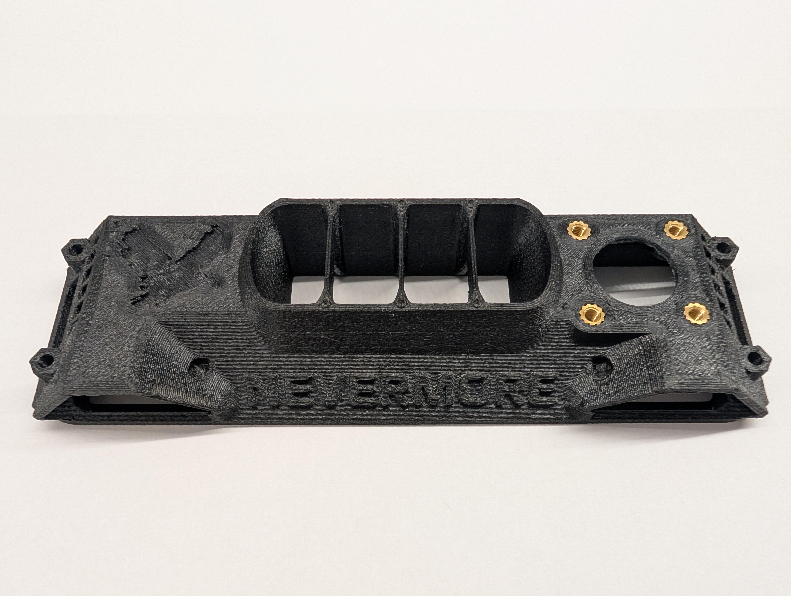
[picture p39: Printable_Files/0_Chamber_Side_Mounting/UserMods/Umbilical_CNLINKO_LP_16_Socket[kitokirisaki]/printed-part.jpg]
Printed Part

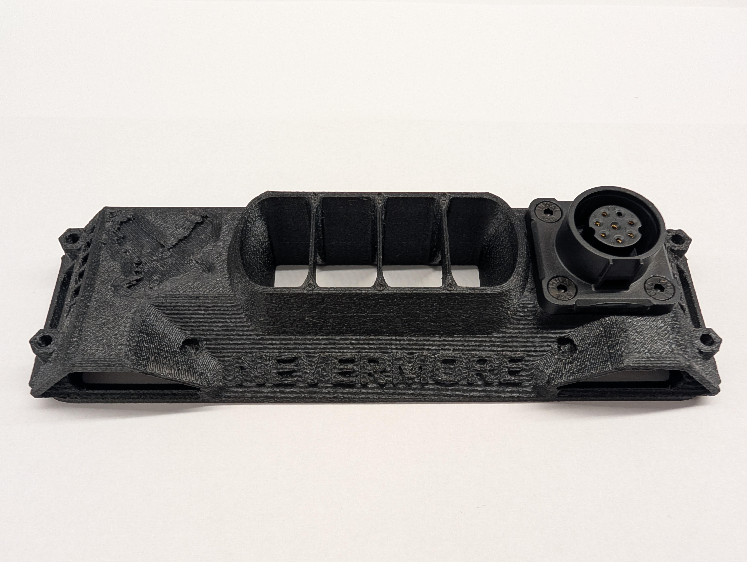
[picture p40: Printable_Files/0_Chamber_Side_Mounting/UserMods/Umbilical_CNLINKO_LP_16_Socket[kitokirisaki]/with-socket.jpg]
With Socket

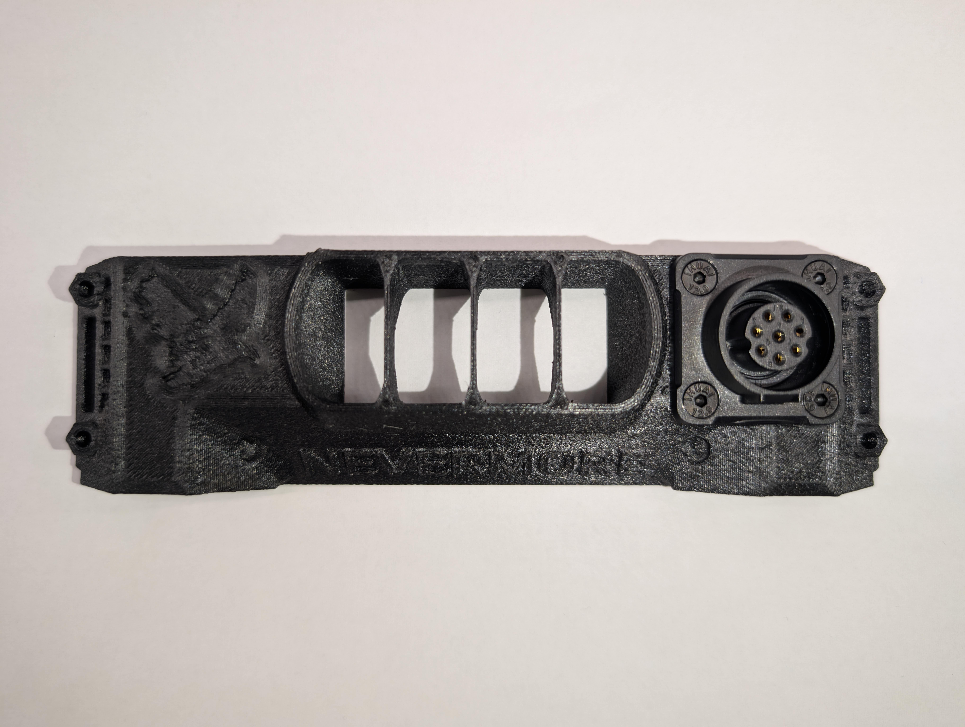
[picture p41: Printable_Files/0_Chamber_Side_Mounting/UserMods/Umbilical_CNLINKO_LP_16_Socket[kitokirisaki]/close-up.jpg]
Close Up

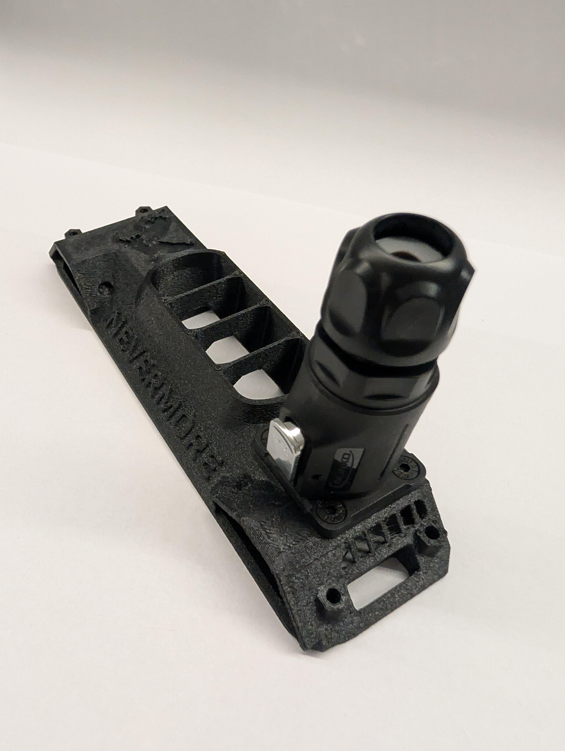
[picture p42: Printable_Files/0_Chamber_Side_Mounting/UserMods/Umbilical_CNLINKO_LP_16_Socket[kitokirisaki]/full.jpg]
Full


---

## Support & Contributions

If you have any questions or suggestions, feel free to ask me (@kito_was_gone) in the Nevermore Discord. Contributions and improvements are always welcome!

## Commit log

2025-04-05 orientation fixes
    [1,28_Hinge_noTouch.step, 17mm_CPAP_Tube.step, 17mm_ID_CPAP_intake_tube.step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]
2025-04-10 from stealthmax v1
    [CPAP_Tube_2020_Extrusion_Mount.stl]
2025-05-03 fixes alignments
    [PUG_Port_Cover.step]
2025-05-14 updated tolerances
    [Back_Panel_Spacer[for_3mm_back_panel_thickness].stl]
2025-05-23 separates files + minor fixes
    0.15mm tighter latches, minor neopixel holder overhang tweak
2025-05-23 hexopus for sensor sandwich
    regular pieces hexopus is for isiktech single board sensors
    [Sensor_Sandwich_Hexopus.stl]
2025-05-23 plugs the side bowden PC4 hex intakes if not used
    [Side_Bowden_Hex_Plug(2x).step]
2025-07-12 Initial commit of CNLINKO LP-16 Umbilical Mod (#2)
    [umbilical_cnlinko_lp16_intake.step, umbilical_cnlinko_lp16_intake.stl]
2025-10-24 Added a CnLinko LP-12 mount
    [umbilical_cnlinko_lp12_intake.step]
